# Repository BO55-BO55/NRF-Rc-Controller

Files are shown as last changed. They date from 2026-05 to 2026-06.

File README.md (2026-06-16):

#  What is the project? 
  
This Project will be an NRF Controller but I want to to build a reliable one not a cheap DIY Rc controller in order to control My future project RC Plane and I want to build the project to be modular and easy to remake and develop/enhance whether with new components or new design for the body

---
 #  Why this project? 
I am from Tunisia ,north africa and we don't really have plenty of choices when its about choosing Rc controllers and I can't just import from europe or US 
So I am obliged to go with DIY and making it myself if I really want to follow my Rc hobbys However I have already built several Ec controllers but they were not really reliable and useful I built projects like this 


So cheap and unrelaible design and I want to do a version better and more argonomic I want to achive deisgn like this
image (1)

---

# CAD 
Final model 
Rc Controller V2 v3
Rc Controller V2 v3s
Rc Controller V2 v3h
Rc Controller V2 v3n
# Modules 
Joystick Module 
Joystick Module v1
Joystick Module ph 2
Buttons module 
buttons_module_v1_2026-May-25_09-43-39AM-000_CustomizedView54042213613
ffef9de6-67cd-4a47-a419-cfe457113b4f
Buttons_linaire_module_v1_2026-May-25_10-12-05AM-000_CustomizedView13456841876
f927a5b6-0077-4a14-99c6-ccd561592a5c
Brain Module 
Brain module v4
Brain module v40

# Electronics 
circuit_image (2)

5317f0e4-b963-4ad5-b4cc-3b0a5c2786c2
57def5b3-26fa-4768-aeef-6f3b6edfdd9f

# DEMO VIDEO
https://youtu.be/7rbx3s6sY6w

# BOM 
## Bill of Materials (BOM)

| Item | Quantity | Unit Price (USD) | Total Price (USD) | AliExpress Link |
|---|---:|---:|---:|---|
| Joystick Module | 1 | $5.72 | $5.72 | [Link](https://ar.aliexpress.com/item/1005008290657090.html) |
| Rotary Encoder Module | 1 | $6.00 | $6.00 | [Link](https://ar.aliexpress.com/item/1005001423308166.html) |
| Linear Potentiometer | 1 | $5.38 | $5.38 | [Link](https://ar.aliexpress.com/item/1005007393023800.html) |
| 10K Potentiometer | 1 | $0.30 | $0.30 | [Link](https://ar.aliexpress.com/item/1005005709041048.html) |
| 1.77 TFT 160x128 Display (ST7735) | 1 | $1.86 | $1.86 | [Link](https://ar.aliexpress.com/item/1005006309710568.html) |
| AMS1117 Module | 1 | $0.93 | $0.93 | [Link](https://ar.aliexpress.com/item/1005011921793796.html) |
| 6x6 Tactile Button | 4 | $4.16 | $4.16 | [Link](https://ar.aliexpress.com/item/1005010093330224.html) |
| 18650 Battery Cell | 2 | $1.71 | $3.42 | [Link](https://ar.aliexpress.com/item/1005011974701653.html) |
| 18650 2-Cell Battery Holder | 1 | $0.97 | $0.97 | [Link](https://ar.aliexpress.com/item/4000859859685.html) |
| Heat Set Inserts (M3) | 1 | $1.47 | $1.47 | [Link](https://ar.aliexpress.com/item/1005009760789373.html) |
| On/Off Switch | 1 | $5.38 | $5.38 | [Link](https://ar.aliexpress.com/item/1005008525408190.html) |
| XH2.54 Connector Kit | 1 | $7.26 | $7.26 | [Link](https://ar.aliexpress.com/item/1005006498660940.html) |
| ESP32-S3 Development Board | 1 | $13.82 | $13.82 | [Link](https://ar.aliexpress.com/item/1005010195145577.html) |
| 10x10 cm Perfboard | 1 | $4.69 | $4.69 | [Link](https://ar.aliexpress.com/item/1005007876120447.html) |
| Toggle Switch | 1 | $5.89 | $5.89 | [Link](https://ar.aliexpress.com/item/1005002461701337.html) |
| Filament | 1 | $30.08 | $30.08 | [Link](https://ar.aliexpress.com/item/1005001298882187.html) |
| **PROJECT TOTAL** |  |  | **$97.33** |  |

# NB !!!
I used AI in the final code to optimize the Screen UI and the logic of the code

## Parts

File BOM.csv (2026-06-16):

Item | Quantity | Unit Price (USD) | Total Price (USD) | AliExpress Search Link
Joystick Module | 1 | 5.72 | 5.72 | https://ar.aliexpress.com/item/1005008290657090.html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
Rotary Encoder Module | 1 | 6.00 | 6.00 | https://ar.aliexpress.com/item/1005001423308166.html
Linear Potentiometer | 1 | 5.38 | 5.38 | https://ar.aliexpress.com/item/1005007393023800.html
10K Potentiometer | 1 | 0.30 | 0.30 | https://ar.aliexpress.com/item/1005005709041048.html
1.77 TFT 160x128 Display (ST7735) | 1 | 1.86 | 1.86 | https://ar.aliexpress.com/item/1005006309710568.html
AMS1117 Module | 1 | 0.93 | 0.93 | https://ar.aliexpress.com/item/1005011921793796.html
6x6 Tactile Button | 4 | 4.16 | 4.16 | https://ar.aliexpress.com/item/1005010093330224.html
18650 Battery Cell | 2 | 1.71 | 3.42 | https://ar.aliexpress.com/item/1005011974701653.html
18650 2-Cell Battery Holder | 1 | 0.97 | 0.97 | https://ar.aliexpress.com/item/4000859859685.html
Heat Set Inserts (M3) | 1 | 1.47 | 1.47 | https://ar.aliexpress.com/item/1005009760789373.html
On/Off Switch | 1 | 5.38 | 5.38 | https://ar.aliexpress.com/item/1005008525408190.html
XH2.54 Connector Kit | 1 | 7.26 | 7.26 | https://ar.aliexpress.com/item/1005006498660940.html
ESP32-S3 Development Board | 1 | 13.82 | 13.82 | https://ar.aliexpress.com/item/1005010195145577.html
10x10 cm Perfboard | 1 | 4.69 | 4.69 | https://ar.aliexpress.com/item/1005007876120447.html
Toggle Switch | 1 | 5.89 | 5.89 | https://ar.aliexpress.com/item/1005002461701337.html
Filament | 1 | 30.08 | 30.08 | https://ar.aliexpress.com/item/1005001298882187.html
PROJECT TOTAL |  |  | 97.33

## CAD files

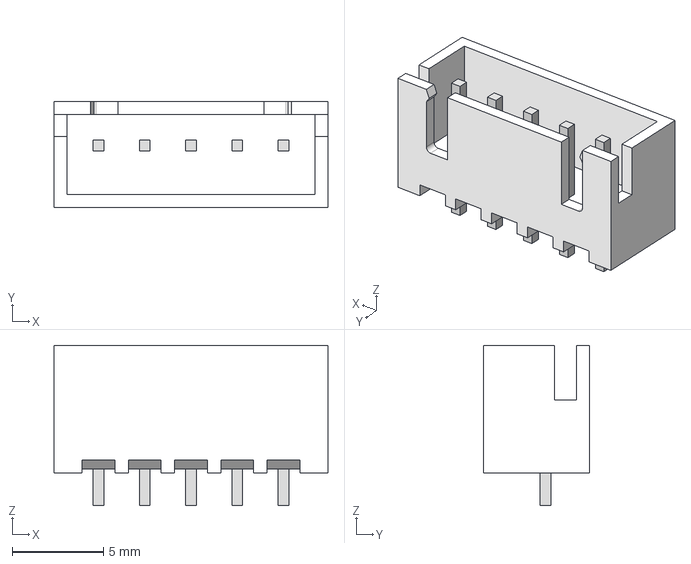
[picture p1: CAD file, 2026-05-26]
CAD/Components/User Library-XH2_54-5P-1 v1.step
15.0 x 5.80 x 8.80 mm

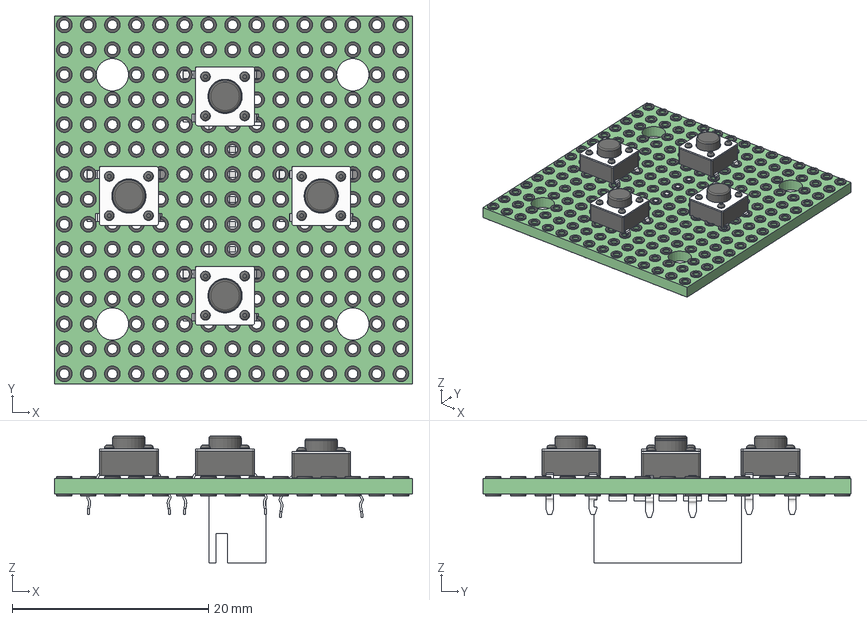
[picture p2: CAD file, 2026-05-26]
CAD/My designs/buttons module v2.step
36.5 x 37.5 x 12.9 mm
2F718D9C-4734-4DA7-AE3D-5C21C155A767
кнопка маленькая x 4
perfboard v2

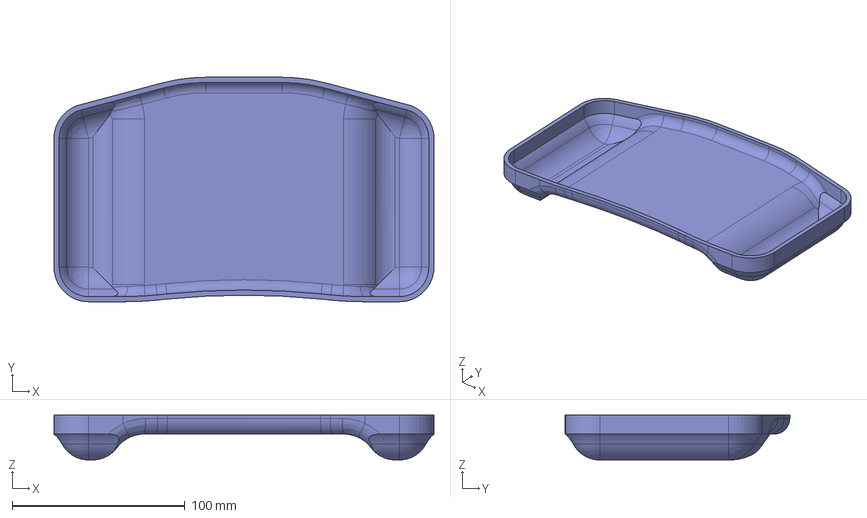
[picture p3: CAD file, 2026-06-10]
CAD/My designs/Main body/Base.step
220.0 x 130.0 x 26.0 mm

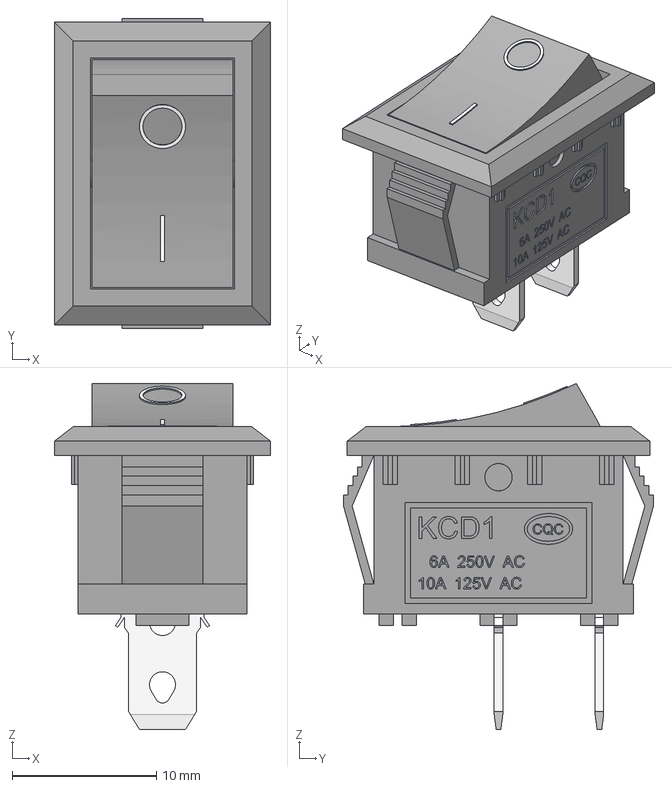
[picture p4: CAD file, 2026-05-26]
CAD/Components/kcd1_a v1.step
15.0 x 21.5 x 24.0 mm
Blade_001
Blade_002
Base_w_text
knob001

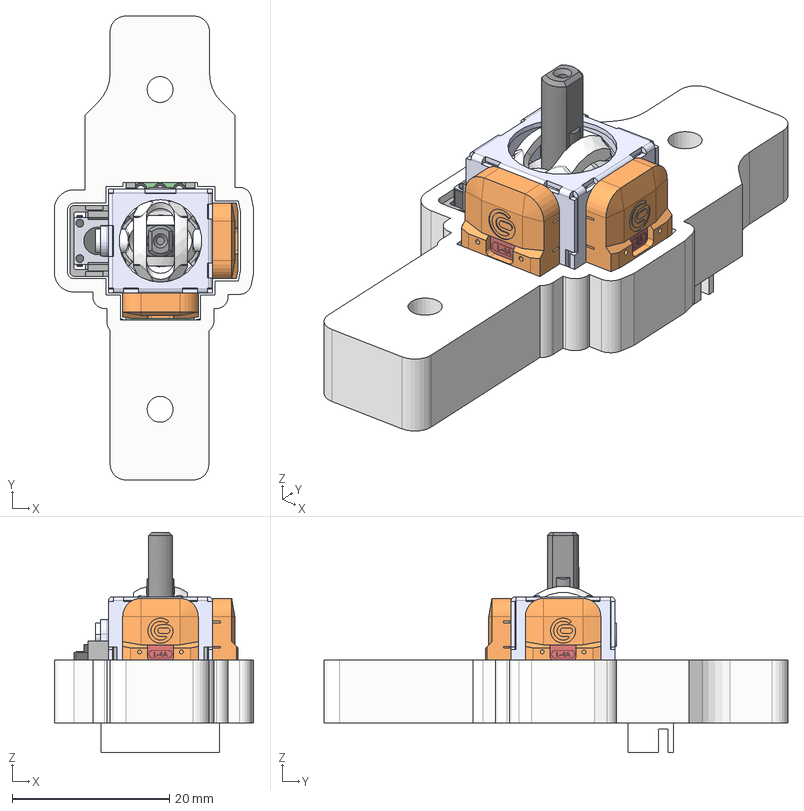
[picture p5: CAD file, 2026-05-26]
CAD/My designs/Joystick Module v2.step
25.4 x 59.0 x 28.0 mm
perfboard v2
Base
Resorte
Pulsador 6x6 5mm
Muelle
X
Stich
Base_Iman x 2
Iman x 2
Y
Palo
Eje
Sensor x 2
2F718D9C-4734-4DA7-AE3D-5C21C155A767

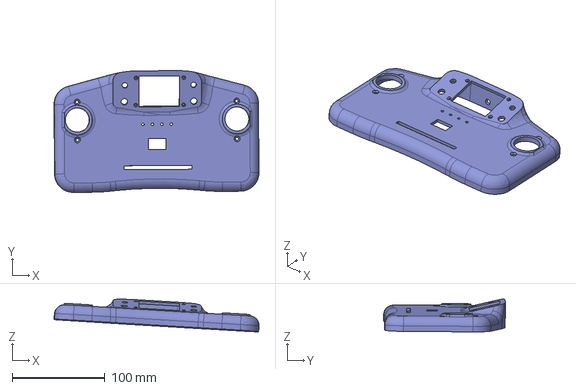
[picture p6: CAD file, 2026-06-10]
CAD/My designs/Main body/TOP.step
220.5 x 131.0 x 35.3 mm

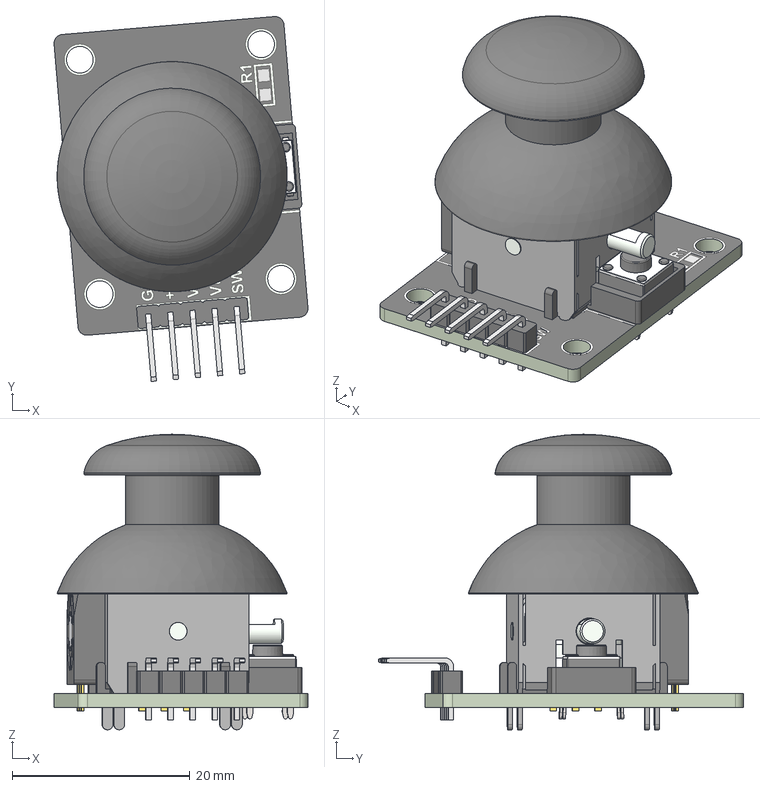
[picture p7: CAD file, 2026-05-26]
CAD/Components/KY-023_Joystick-Module v2.step
28.6 x 41.1 x 33.3 mm
PCB
5x_Ang_Conn
Baseplate
Case
Rotator-Unit
Potentiometer_01
Potentiometer_02
Tactile-Switch
Thumb-Button

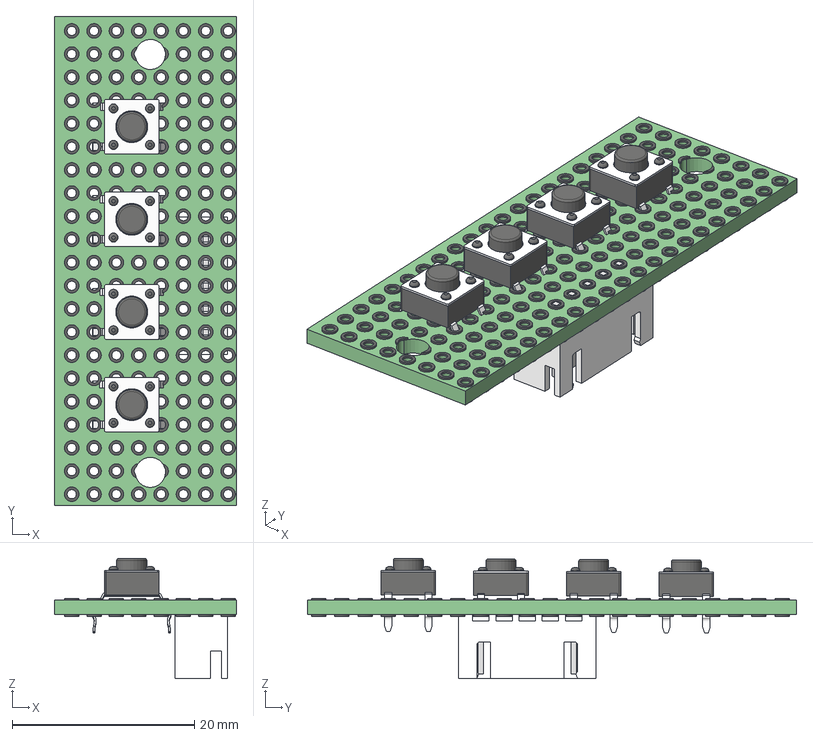
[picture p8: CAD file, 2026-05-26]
CAD/My designs/Buttons linaire module v3.step
20.0 x 53.6 x 13.2 mm
2F718D9C-4734-4DA7-AE3D-5C21C155A767
кнопка маленькая x 4
perfboard v2

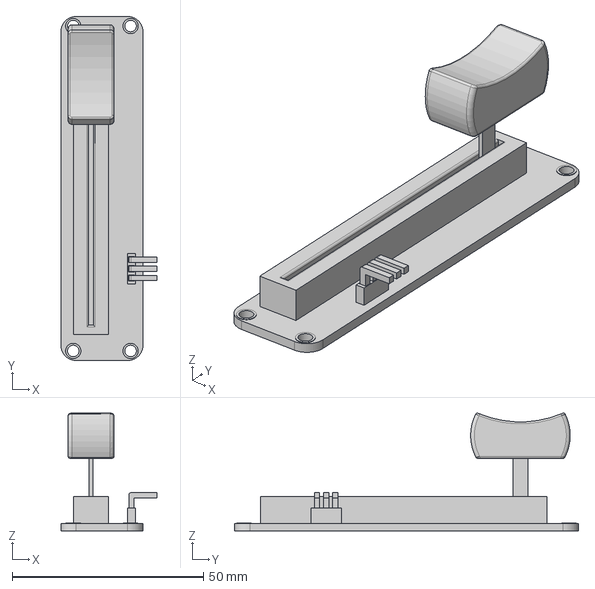
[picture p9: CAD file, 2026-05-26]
CAD/Components/Potenciometro v1.step
25.2 x 90.0 x 30.9 mm

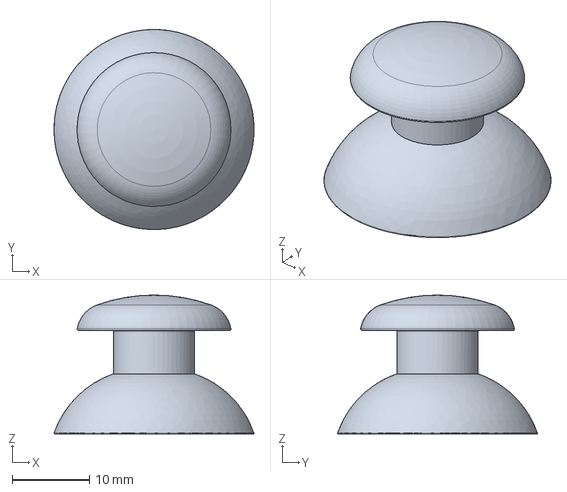
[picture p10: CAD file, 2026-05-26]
CAD/Components/Thumb-Button v1.step
25.9 x 25.9 x 18.0 mm

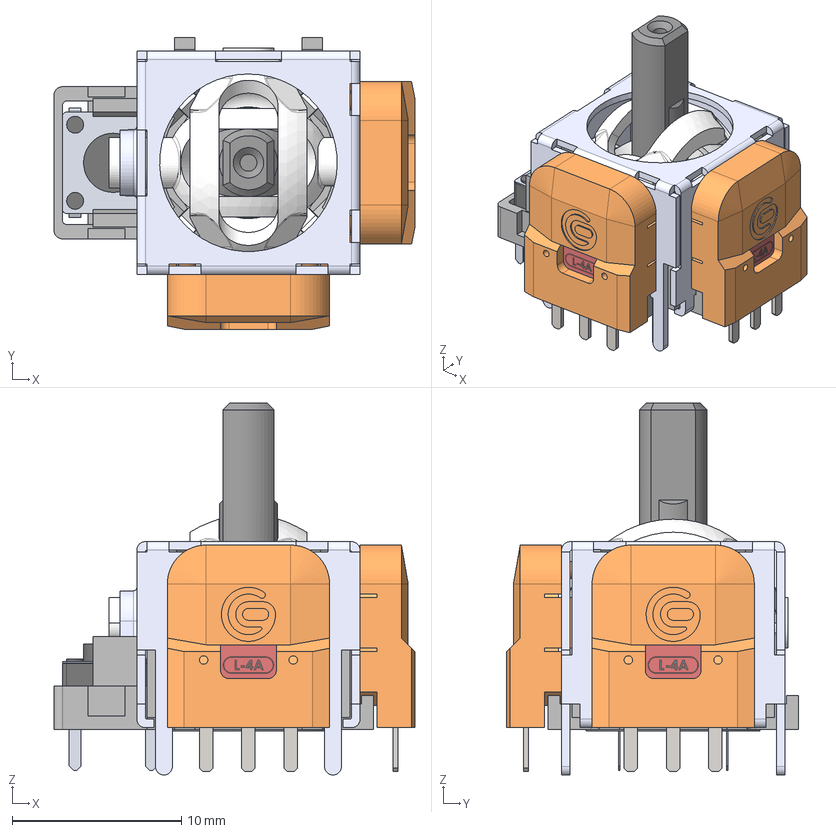
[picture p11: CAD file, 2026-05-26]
CAD/Components/Joystick_Hall_PS5 v2.step
21.4 x 17.3 x 22.0 mm
Base
Resorte
Pulsador 6x6 5mm
Muelle
X
Stich
Base_Iman x 2
Iman x 2
Y
Palo
Eje
Sensor x 2

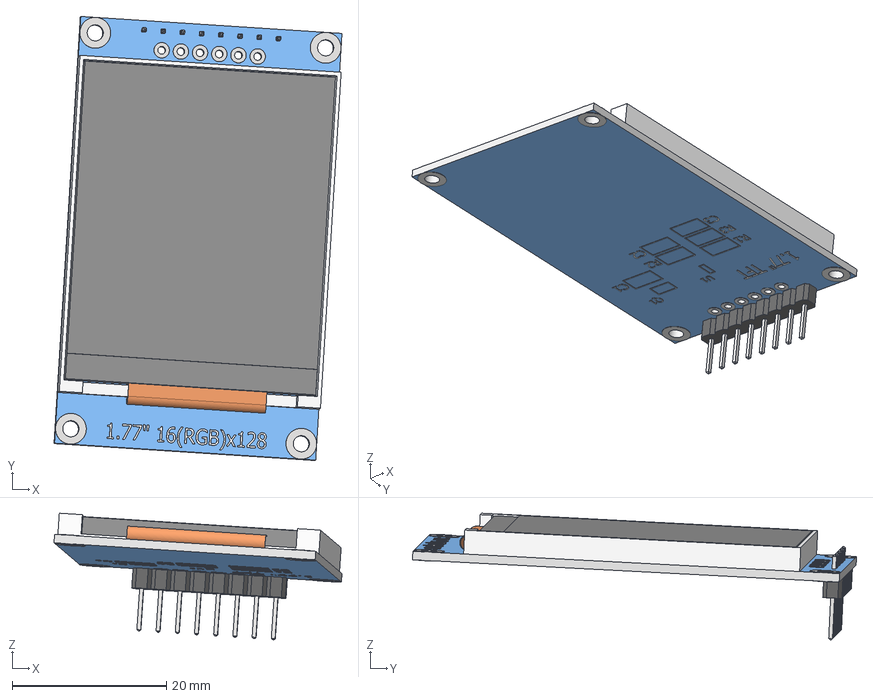
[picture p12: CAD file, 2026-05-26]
CAD/Components/1e77-TFT-160x128 v2.step
37.3 x 57.6 x 16.4 mm

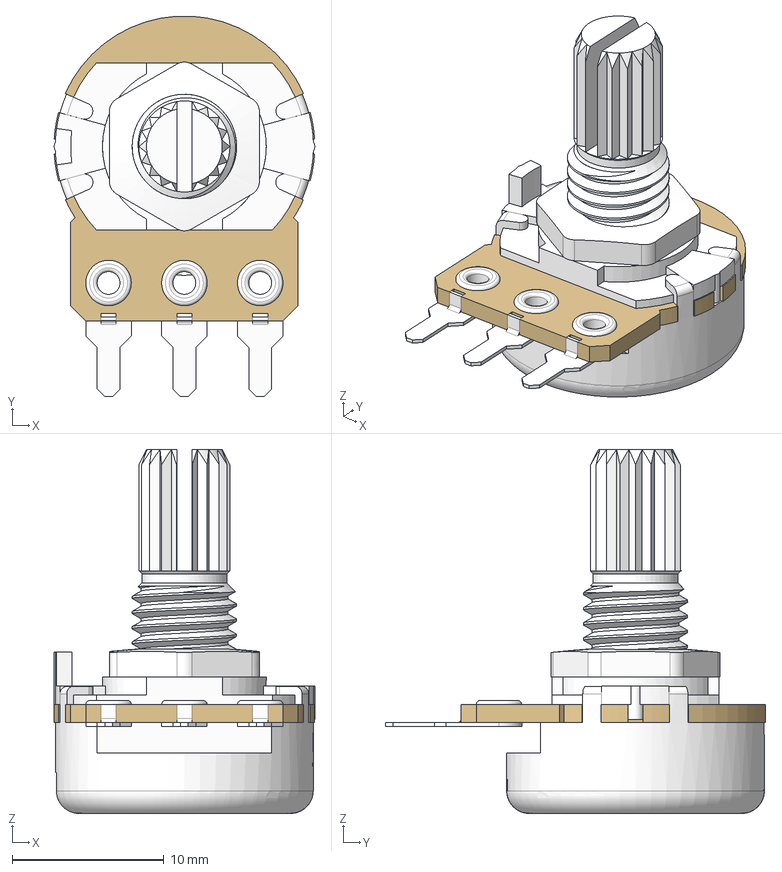
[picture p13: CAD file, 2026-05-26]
CAD/Components/potentiometer v1.step
17.2 x 25.1 x 24.0 mm

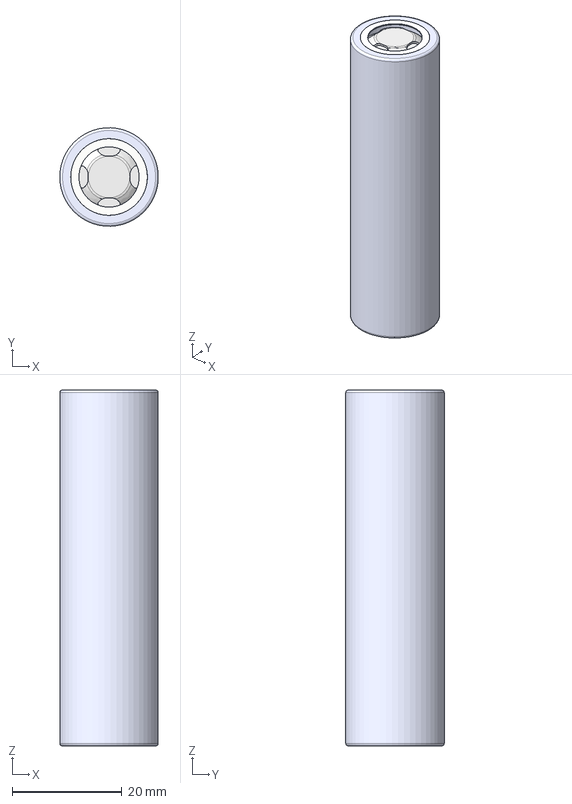
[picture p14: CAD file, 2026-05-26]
CAD/Components/Cell 18650 v1.step
18.0 x 18.0 x 65.0 mm
battery 186501^battery 18650(2)_battery 18650
battery 186502^battery 18650(2)_battery 18650
battery 186503^battery 18650(2)_battery 18650
battery 186504^battery 18650(2)_battery 18650

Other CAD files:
CAD/Components/MPU v1.step
CAD/Components/SPDT-Print-Switch v1.step
CAD/Components/Potentiometer knob_A21x17-PK-AB-K-I v1.step
CAD/Components/button 6x6 v1.step
CAD/Components/NRF24L01L+Antenna v2.step
CAD/My designs/Main body/Base.f3d
CAD/My designs/Main body/TOP.f3d

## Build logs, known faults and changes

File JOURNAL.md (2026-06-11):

# DAY 1
So Today I stated my project the NRF Rc controller and I started with looking in several other design in order to choose what exactly want and inspire from them and I really liked those one





Then I moved to the part of looking for components that I will use in the cad so I passed the rest of time looking in local shops for models and searching in grabcad for the components that I will use and I ended up finding all of those in order to make the task of 3d 
modeling the body easier for me this all those components





The next step I will draw the idea of the design that is in my head and when I finally chose a model I will start cading the actual body

# DAY 2
Today I started the real cad using fusion 360
And I decided to start with the Joystick
As I told you last time I want the project to be modular where I can change the component in the project whenever I want so this why i won't solder completely anything I will make everything modular with xh2.54 connector



I want to make everything with custom modules like this one



So I started with making a perfboard I did a big one and I will cut it to whatever size I will need



and then cut and use it in the module of the joystick
then I designed a 3d printed body for the module for protection and good look hhh




# DAY 3

So today I move to work on the next module and i went with Buttons module I will do two modules one that is diamond shape and one linear shape so I imported the buttons and the pegboard that I already caded last time and put the buttons and the XH2.54 connector and cut the board to match the size that I need and then I added holes in order to be able to fix it in the body with M3 screws and two other holes for passing the wires to the XH2.54 connector when I do soldering I ended up with this design for the diamond shape




And this is the shape of the linear shape




# DAY 4 
So as I finished design the modules that i will be using in the controller I decided to move to the part of the design of the controller where I stated with looking in Youtube for other design in order to inspire how the design will exactly be and some solutions to fix the components and I really like this one in how to fix the components
I will go with a solution like this



Inspired from *RCMakerLab * youtube video when he built his own rc controller
Then I putted the components in one cad and start looking for the best arrangement possible that suits my taste and my need and after a lot of trials and placement I ended up with this placement



Then I went to gemini to help me using nano banana to genrate how the final look after the long hours of cad will look like and see if it will look good or no before its too late and after some trials and failed generation I ended with this two photos from gemini and I think that it looks even better from real commercial one because I went with details like how the shape lead to the the screen because I really don't like the the middle screen in the controllers and I went with joysticks up and buttons low and throttles and potentiometer next the screen I will start designing next like version as a protype of the prototype because the final version will be incredibly modular like you can remove the joystick and add buttons or better joysticks like the Framework laptops exactly




# DAY 5
So today I stated the design and I think it will be the most difficult part of the project because i should take care of all the details so I putted the components and module that I already designed and started modeling so I decided to start with basic design and add details with time because i am not that good at making agronomic look and design So using the help of the image that I generated last time I wans able to get and achieve this design





# DAY 6

Today I started working with making a GitHub Project for this project in order to gain time in the future before things get complicated and be no longer able to make the project and upload everything so I went with a read me that I will complete as the project go on



and I uploaded all the CAD components that I used




# DAY 7

After putting the project on GitHub I back to design to the controller and I decided to change everything and redesign the controller from the scratch and the reason that I taught that I will do the electronics then work on details whish is stupid because I won't be able to edit after so I started working with details and general shape then moved to the electronics and it worked fantastic I went from making general shape like this






For details
I changed the way how i fixed the joystick I went with this solution that I will explain it in next journal



# DAY 8 

Today I wanted to take a short brake from the design and as I back home I went with making the finished design of the joystick module and I ended with this amazing results
To be honest I am verry proud of My soldering
And after doing the first one I had to do some correction with with the soldering iron by melting some plastic So this why I added some adjustments to the design and printed for the second one and It went perfect after two failed prints




*NB : one of my journals got 4h and 24 min instead of the half I don't know what is the problem but I tried to reach the help and they told to mention the problem in my journals *

# DAY 9 

Today was a big day with a lot of work
So yesterday I finished the design However my two hours session was gone due to a bug in the lapse
Anyway I ended up with this final design for the top



and I 3d printed the file after half hour of slicing
And i got this




This part was Yesterday But I lost the two hours of recording
Today I finally stated the assembly and making the project in real life and seeing comes true so I got some little problems with tolerances So I went with sanding
then I did make the module of the buttons




And after assembling the parts together I got this look



And btw I changed one of the potentiometer with one KY040 but no changes is in the deign
Then I started soldering the main board wish is esp32-s3 with connectors in order to make my modularity plan and be able to attach and dethatch anytime I want to I didn't finfish the board but this is the results for now




and the I moved the soldering wires with the XH2.54 connectors in order to be able to start testing my modules tomorrow and I got those wires for now



# DAY 10

As yesterday I started soldering I was really confused in soldering because I didn't have a clean design to follow so I decided to go with cirkit designer and make my project there wish to my surprise was really good I used to do this job with canva wish was really hard an time consuming
And I think design like this will be really helpful in the GitHub read me because it well help understand more what I did instead of just numbers
This was the final results



# DAY 11

Today and I finished the cad of the brain board
I did it in order to know how to solder the rest of the connectors XH2.54 taking in consideration the little space that I have because I already cut the board and It will eventually help in cading the base part of the controller
After I finished the cad I went with soldering the rest of the board and adding new connectors and Soldring the wires following the cirkit design of the last journal
I soldered everything in the board except the encoder connector




# DAY 12

Today I made some progress and I finished a good part of the project I officially finished soldering the part of the brain
I also soldered the screen wires and nrf wires and I made a module for each oh them where I can use it anywhere else I got this a final deign with wires I still have to make and solder the wires of potentiometer and encoder and the bascules







# DAY 13 

Today I didn't do much in this project I tested circuit continuity and I FOUND A LOT OF problems and I will have to resolder a lot of things however the joystick and buttons work fine I did some tests and it worked well



# DAY 14 

Ok so yesterday I didn't do much because I got my soldering Iron broken So I got my friend's iron and I fixed mine
Then I back to the project
When I got my multimeter I was shoked that i soldred both screen module and NRF module wrong I did mistake with the pins and I did oppose the MOSI AND SCK in the board so I changed the pins number 35 and 36 I retotally Soldered the module of nrf because I don't know why but every pin was wrong
Today I went with finishing the soldering and moving to the last part and fix on code when I started testing and looking for pins I discovered that I didn't take into consideration the toggle pins hhhh and I have no connectors for them so I spend some time looking on computer the legitim pins that I can use
then I used a test code and i got things bad



I spent then some amount of time debugging and I found that I can't use the pins number 32 that I used in the code as toggle 2
The solution was too simple I changed the 32 to 21 and did fix the soldering and hopefully everything worked from the toggles to the joysticks and buttons and potentiometer



Then I wanted to do a quick test for the screen However It didn't work and I got this error



And after I spend some time looking for explanation I found that I used the pins 36 and 35 as SPI pins
and I can't use those pins with ESP32S3 16NR8
because its dedicated the flash and other stuff so
Unfortunately I can't use those pins and I have a lot of work to do
And I went to cirkitdesigner and added the toggle



This the look of the project for now




# DAY 15 

At first as I have some problems with my SPI pins because I used pins that are used in flashing the esp32s3 so I used the pins in 40s instead of 30s and I fixed some brooked wires then I spent the rest of the time trying to make the screen work from looking at github to forms to youtube and then finally find a code that worked successfully then I spent some time trying to make nrf work I used a pcb from HOWTOMECHATRONICS as a receiver but even after many trials I couldn't receive the signal and I don't know where is the prob so I decided to take a break and try to move on with the screen and discover how can I use the GFX library to do my desired Menu and tried to use WOOKI in order to simulate the first in order to gain time however I didn't find the ST7735 Module
I think I will go with the OLED screen menu then change some details in the code to adapt to my screen code
(I tried to make my custom Screen on wokwi but still couldn't figuring out how )



this is the screen when it worked



# DAY 16 
Today was the final day where I worked on the nrf until I got it working and then I recorded the demo and post it and some final toutches on the github in order to be able to ship 
this is the demo 

https://www.youtube.com/watch?v=7rbx3s6sY6w

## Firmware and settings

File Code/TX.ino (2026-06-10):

#include <SPI.h>
#include <nRF24L01.h>
#include <RF24.h>
#include <Adafruit_GFX.h>
#include <Adafruit_ST7735.h>

#define ST7735_DARKGREY  0x7BEF

#define SPI_SCK   40
#define SPI_MOSI  41
#define TFT_CS    17
#define TFT_DC    16
#define TFT_RST   18

#define NRF_CE    47
#define NRF_CSN   48
#define NRF_SCK   40
#define NRF_MOSI  41
#define NRF_MISO  42

#define JOY1_X_PIN   1
#define JOY1_Y_PIN   2
#define JOY2_X_PIN   3
#define JOY2_Y_PIN   4
#define POT_PIN      6

#define JOY1_SW_PIN  7
#define JOY2_SW_PIN  8
#define BTN1_PIN     12
#define BTN2_PIN     13
#define BTN3_PIN     14
#define BTN4_PIN     15
#define TOGGLE1_PIN  38
#define TOGGLE2_PIN  21

// ── Tuning ───────────────────────────────────────────
// Joystick center on a 12-bit ADC is ~2048.
// Deadzone: ignore inputs within ±200 of center.
// Pot center: pots usually rest at 0 or 4095, not center.
// Set POT_MIN_MOVE to 50 — any pot reading above 50 is "active".
#define JOY_CENTER    2048
#define JOY_DEAD      200     // joystick deadzone radius
#define POT_MIN_MOVE  50      // pot must be above this to count

Adafruit_ST7735 tft(TFT_CS, TFT_DC, SPI_MOSI, SPI_SCK, TFT_RST);
SPIClass nrfSPI(HSPI);
RF24 radio(NRF_CE, NRF_CSN);

const byte address[6] = "00001";

struct Payload {
  uint16_t joy1x, joy1y;
  uint16_t joy2x, joy2y;
  uint16_t pot;
  uint8_t  buttons;
};

// ── NEW: "most deflected input wins" ─────────────────
// Each joystick axis reports how far it is from center (0–2048).
// The axis with the largest deflection controls the angle.
// Pot overrides everything except buttons.
// Buttons are absolute top priority.
int computeAngle(Payload& d) {

  // --- Step 1: buttons (absolute priority) ---
  if ((d.buttons >> 5) & 1) return 180;
  if ((d.buttons >> 4) & 1) return 120;
  if ((d.buttons >> 3) & 1) return 60;
  if ((d.buttons >> 2) & 1) return 0;
  if ((d.buttons >> 7) & 1) return 135;
  if ((d.buttons >> 6) & 1) return 45;

  // --- Step 2: pot (second priority, only when not centered) ---
  // Pots sweep 0→4095. If yours rests near 2048, lower POT_MIN_MOVE.
  // If yours rests near 0, this is correct as-is.
  if (d.pot > POT_MIN_MOVE) {
    return map(d.pot, 0, 4095, 0, 180);
  }

  // --- Step 3: joysticks — winner = most deflected axis ---
  int axes[4] = { (int)d.joy1x, (int)d.joy1y,
                  (int)d.joy2x, (int)d.joy2y };

  int bestDeflection = JOY_DEAD;  // must beat deadzone to count
  int bestAxis       = -1;

  for (int i = 0; i < 4; i++) {
    int deflection = abs(axes[i] - JOY_CENTER);
    if (deflection > bestDeflection) {
      bestDeflection = deflection;
      bestAxis       = i;
    }
  }

  if (bestAxis >= 0) {
    return map(axes[bestAxis], 0, 4095, 0, 180);
  }

  // --- Step 4: nothing active → hold last angle or center ---
  return 90;
}

// ── Display ──────────────────────────────────────────
#define PIVOT_X  80   // tft.width()/2 for 160px landscape
#define PIVOT_Y  88   // tft.height()-40 gives room for buttons
#define ARM_LEN  45

int  lastAngle   = -999;  // force first draw
bool lastBtns[8] = {};

void drawServoArm(int angleDeg, uint16_t color) {
  float rad = (angleDeg * PI) / 180.0;
  int x2 = PIVOT_X + (int)(ARM_LEN * cos(PI - rad));
  int y2 = PIVOT_Y - (int)(ARM_LEN * sin(rad));
  tft.drawLine(PIVOT_X, PIVOT_Y, x2, y2, color);
  tft.fillCircle(x2, y2, 3, color);
}

void drawStaticUI() {
  tft.fillScreen(ST7735_BLACK);

  tft.setTextColor(ST7735_CYAN);
  tft.setTextSize(1);
  tft.setCursor(10, 4);
  tft.print("SERVO CONTROLLER");
  tft.drawFastHLine(0, 14, 160, ST7735_CYAN);

  // Arc
  for (int a = 0; a <= 180; a += 5) {
    float r = (a * PI) / 180.0;
    int x = PIVOT_X + (int)((ARM_LEN + 8) * cos(PI - r));
    int y = PIVOT_Y - (int)((ARM_LEN + 8) * sin(r));
    tft.drawPixel(x, y, ST7735_DARKGREY);
  }

  tft.fillCircle(PIVOT_X, PIVOT_Y, 4, ST7735_WHITE);

  tft.setTextColor(ST7735_YELLOW);
  tft.setCursor(2,         PIVOT_Y - 6);            tft.print("0");
  tft.setCursor(PIVOT_X-6, PIVOT_Y - ARM_LEN - 10); tft.print("90");
  tft.setCursor(146,       PIVOT_Y - 6);            tft.print("180");

  tft.setTextColor(ST7735_DARKGREY);
  tft.setCursor(2, PIVOT_Y + 10);
  tft.print("J1  J2  B1 B2 B3 B4 T1 T2");
}

void updateAngle(int angle) {
  // Always erase old arm and draw new one — no skip
  if (lastAngle != -999) {
    drawServoArm(lastAngle, ST7735_BLACK);
    // Re-draw the pivot dot in case arm erased it
    tft.fillCircle(PIVOT_X, PIVOT_Y, 4, ST7735_WHITE);
  }
  drawServoArm(angle, ST7735_GREEN);

  // Angle number — clear box first then print
  tft.fillRect(55, PIVOT_Y - 16, 55, 10, ST7735_BLACK);
  tft.setTextColor(ST7735_GREEN);
  tft.setTextSize(1);
  tft.setCursor(55, PIVOT_Y - 16);
  tft.print(angle);
  tft.print(" deg");

  lastAngle = angle;
}

void updateButtons(uint8_t btnByte) {
  const char* labels[] = {"J1","J2","B1","B2","B3","B4","T1","T2"};
  int xPos[] = {2,16,30,42,54,66,78,90};
  int yPos = PIVOT_Y + 20;

  for (int i = 0; i < 8; i++) {
    bool pressed = (btnByte >> i) & 1;
    if (pressed != lastBtns[i]) {
      tft.fillRect(xPos[i], yPos, 12, 8,
                   pressed ? ST7735_GREEN : ST7735_BLACK);
      tft.setTextColor(pressed ? ST7735_BLACK : ST7735_DARKGREY);
      tft.setCursor(xPos[i], yPos);
      tft.print(labels[i]);
      lastBtns[i] = pressed;
    }
  }
}

void setup() {
  Serial.begin(115200);

  int btnPins[] = {JOY1_SW_PIN, JOY2_SW_PIN,
                   BTN1_PIN, BTN2_PIN, BTN3_PIN, BTN4_PIN,
                   TOGGLE1_PIN, TOGGLE2_PIN};
  for (int p : btnPins) pinMode(p, INPUT_PULLUP);

  tft.initR(INITR_BLACKTAB);
  tft.setRotation(1);
  drawStaticUI();

  nrfSPI.begin(NRF_SCK, NRF_MISO, NRF_MOSI, NRF_CSN);
  if (!radio.begin(&nrfSPI)) {
    tft.setTextColor(ST7735_RED);
    tft.setCursor(20, 55);
    tft.print("NRF24 FAIL!");
    Serial.println("NRF24 not detected!");
    while (1) delay(500);
  }

  radio.openWritingPipe(address);
  radio.setPALevel(RF24_PA_LOW);
  radio.setDataRate(RF24_250KBPS);
  radio.stopListening();

  tft.setTextColor(ST7735_GREEN);
  tft.setCursor(45, 55);
  tft.print("TX READY");
  delay(1000);
  drawStaticUI();
  updateAngle(90);  // draw arm at center immediately
}

void loop() {
  Payload data;
  data.joy1x = analogRead(JOY1_X_PIN);
  data.joy1y = analogRead(JOY1_Y_PIN);
  data.joy2x = analogRead(JOY2_X_PIN);
  data.joy2y = analogRead(JOY2_Y_PIN);
  data.pot   = analogRead(POT_PIN);

  data.buttons = 0;
  data.buttons |= (!digitalRead(JOY1_SW_PIN)) << 0;
  data.buttons |= (!digitalRead(JOY2_SW_PIN)) << 1;
  data.buttons |= (!digitalRead(BTN1_PIN))    << 2;
  data.buttons |= (!digitalRead(BTN2_PIN))    << 3;
  data.buttons |= (!digitalRead(BTN3_PIN))    << 4;
  data.buttons |= (!digitalRead(BTN4_PIN))    << 5;
  data.buttons |= (!digitalRead(TOGGLE1_PIN)) << 6;
  data.buttons |= (!digitalRead(TOGGLE2_PIN)) << 7;

  int angle = computeAngle(data);

  // Debug — open Serial Monitor to verify values are changing
  Serial.print("joy1x="); Serial.print(data.joy1x);
  Serial.print(" joy1y="); Serial.print(data.joy1y);
  Serial.print(" joy2x="); Serial.print(data.joy2x);
  Serial.print(" joy2y="); Serial.print(data.joy2y);
  Serial.print(" pot=");   Serial.print(data.pot);
  Serial.print(" btns=");  Serial.print(data.buttons, BIN);
  Serial.print(" → angle="); Serial.println(angle);

  updateAngle(angle);
  updateButtons(data.buttons);
  radio.write(&data, sizeof(data));

  delay(30);
}
